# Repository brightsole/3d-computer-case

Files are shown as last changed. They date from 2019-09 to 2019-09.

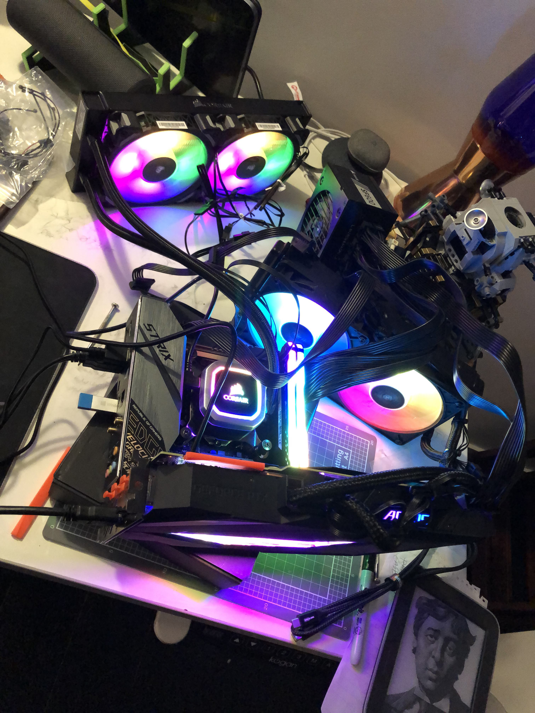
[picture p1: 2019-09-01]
photos/on-box-build.jpg

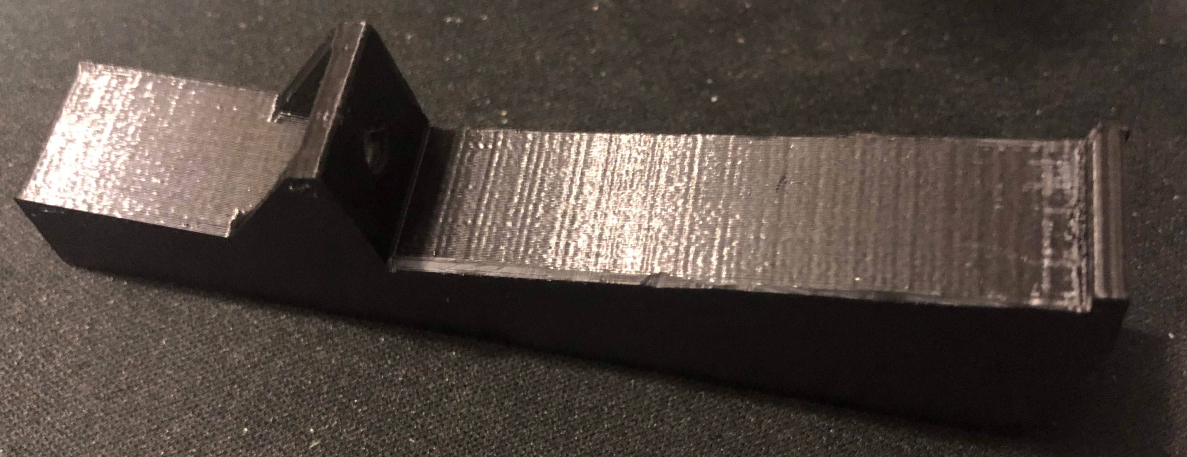
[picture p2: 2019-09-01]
photos/fan-foot-issues.jpg

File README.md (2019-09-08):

# 3d-computer-case

- [x] Describe
	- as small as possible to fit the mini-itx theme
	- hinge between mobo + gpu cowling & fan tower
	- dual fans in rear air column
	- cable hinge cowling
	- fully 3d printed V1
	- V2 more interconnected design with 3d printed moulds for fiberglass parts

- [x] buy parts [part picker basics](https://au.pcpartpicker.com/list/t6MXKB)

- [x] prep work
	- [x] connect all parts on-box build [photo](./photos/on-box-build.jpg)
	- [x] re-mount ram to solve post issue
	- [x] install os
	- [x] run benchmark

- [ ] Design V1
	- [x] mobo block
		- [x] base screw plate
	- [ ] gpu block
		- [x] base insert rest plate
		- [ ] power access block
	- [ ] hinge area
	- [x] interconnectors for blocks & block feet
	- [ ] flexible hinged cowling for watercooling channels

- [ ] Redesign issues found in V1
	- [x] mobo block [multiple](./photos/mobo-block-width-issues.jpg) [issues](./photos/mobo-block-screw-issue.jpg)
		- [x] too wide by 10mm 
		- [x] screw body width too small by 1mm
		- [x] under-gpu height too high by 1mm
		- [x] under-cowling support too short by 1.5mm
	- [x] mobo block [cowling support height issue](./photos/mobo-block-cowling-support-height-issue.jpg)
		- [x] under-cowling support now too high, especially to screw on back ([fixed by grinding, model corrected in V1.3](./photos/mobo-block-height-and-screw-issue.jpg))
		- [ ] TO FIX IN V2: screw walls have very little lateral strength because of vertical printing
	- [x] fans base foot [mild issues](./photos/fan-foot-issues.jpg)
		- [x] too narrow by 0.5mm
		- [x] front lip too short by 1.5mm
		- [x] sharp edges with elephant foot overhang, and screw height
	- [x] gpu block [major issue](./photos/gpu-block-issue.jpg)
		- [x] metal cowling hole too narrow

- [x] Print
	- [x] mobo block V1[.1](./files/mobo-holder-v1.1.stl)
	- [x] mobo block V1[.2](./files/mobo-holder-v1.2.stl) redesign
	- [x] fans base foot V1[.1](./files/fan-foot-v1.1.stl)
	- [x] fans base foot V1[.2](./files/fan-foot-v1.2.stl) redesign
	- [x] gpu block V1[.1](./files/gpu-block-v1.1.stl)

- [x] Describe Problems with V1
	- layout [very cluttered](./photos/v1-full-layout.jpg)
	- water cooling cables fight for space with psu cables
	- large space caused by flat gpu extension
	- good airflow; no dust protection
	- no blocks connected
	- no way to move, exposed dangerous places to touch
	- power switches not designed into any block
	- 3d printed plastic not durable
	- neglected to design psu connection block
	- hinge ideas scrapped after seeing pipe cluster

---

- [x] Describe V2
	- rotate cooling block 90° to reduce pipe congestion
	- elevate mobo and reduce lateral distance to gpu
	- connect gpu & mobo blocks
	- add handle to top of mobo/cooling tower
	- shorten cables, or create cable hiding tower hinge
	- add cutout to gpu block to insert power switches

- [ ] Redesign V2
	- [ ] back support structure with window for mobo
	- [ ] hinged front cowling for mobo
	- [ ] hollow structure for gpu & power switches

- [ ] print V2
	- [ ] gpu 1 || 2
	- [ ] mobo 1 || 3
	- [ ] psu connection system
	- [ ] cooling tower connectors/supports
	- [ ] handle

---

- [x] Describe V3
	- create designs that are predominantly moulding
	- design 3d printed parts that insert into fiberglass frame
	- buy clear pla+ or PETG for case colour spice
	- larger pieces in the shape of V2, but made of fiberglass with printed inserts, and structural rigidity created by folds

- [ ] Redesign V3

- [ ] print V3 mold pieces

- [ ] Print V3 inserts

---

- [ ] Cleanup

- [ ] Assemble
		- [x] [V1](./photos/v1-full-layout.jpg)

- [ ] Finish

- [ ] Photograph

- [ ] Thingiverse

- [ ] Software
	- [x] [Ninite - Install or Update Multiple Apps at Once](https://ninite.com/)
	- [x] Docker for win10
	- [x] WSL2 using `fast-ring` win10
	- [x] Ubuntu
	- [x] Zsh
	- [ ] our git/npm keys

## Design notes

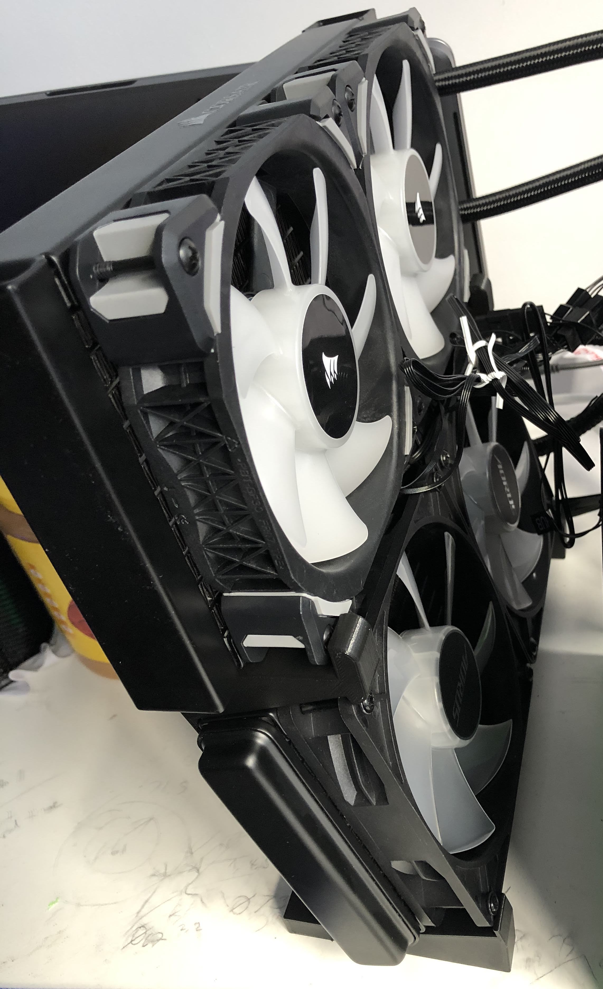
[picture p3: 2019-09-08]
photos/fan-block-front.jpg

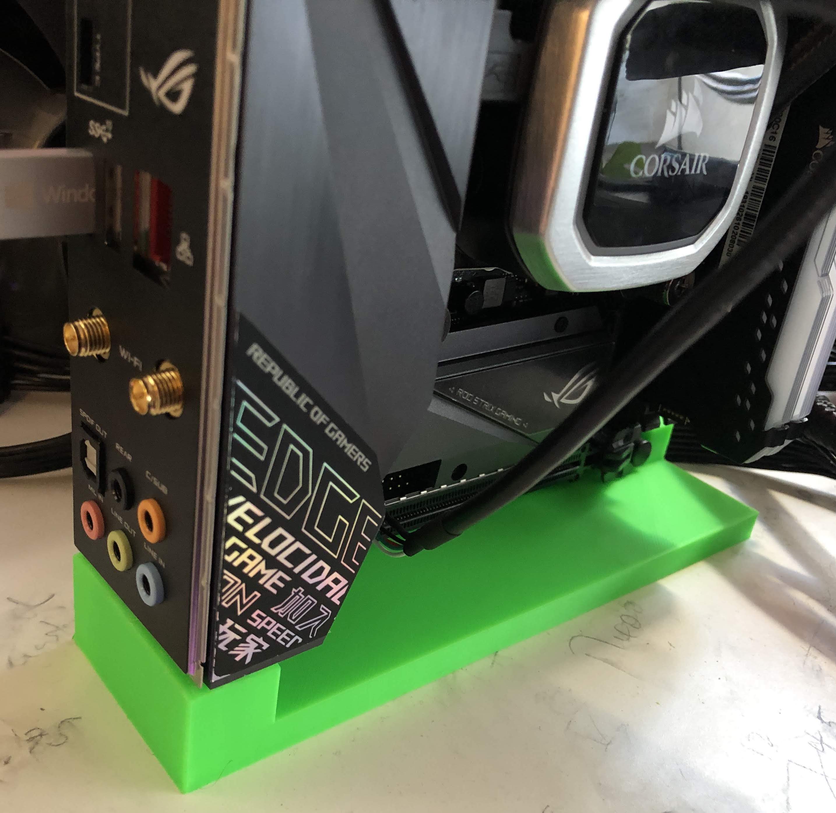
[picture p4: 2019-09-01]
photos/mobo-block-freestanding.jpg

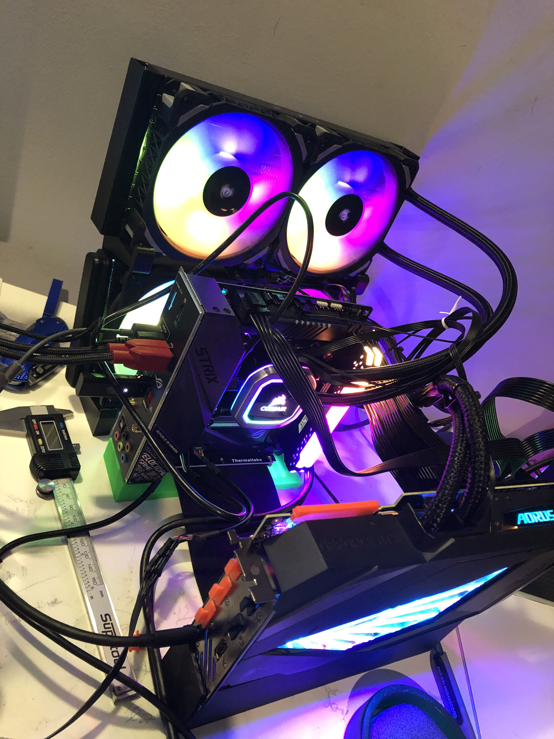
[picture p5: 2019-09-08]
photos/v1-full-layout.jpg

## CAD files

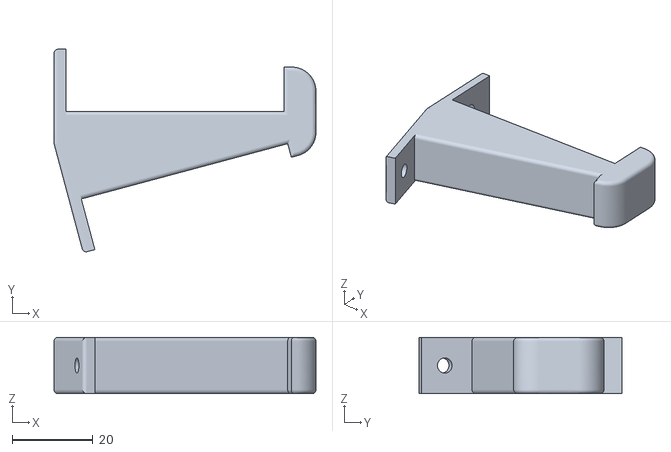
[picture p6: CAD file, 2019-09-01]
files/fan-hinge-v1.1.stl
65.0 x 50.3 x 14.0

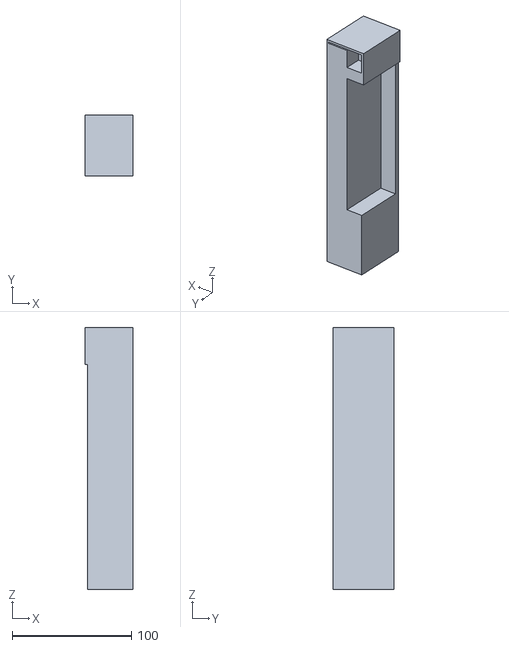
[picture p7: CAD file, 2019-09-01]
files/gpu-block-v1.1.stl
40.0 x 51.0 x 220.0

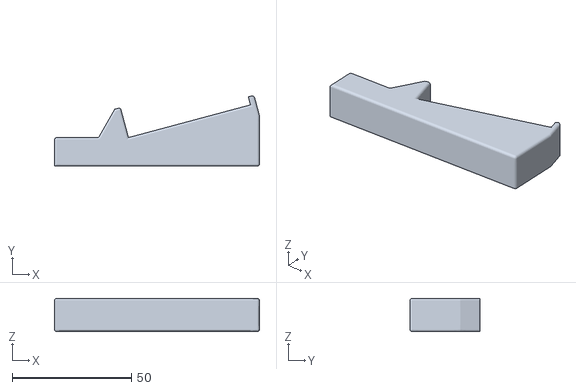
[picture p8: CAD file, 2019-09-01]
files/fan-foot-v1.2.stl
86.1 x 29.5 x 14.0

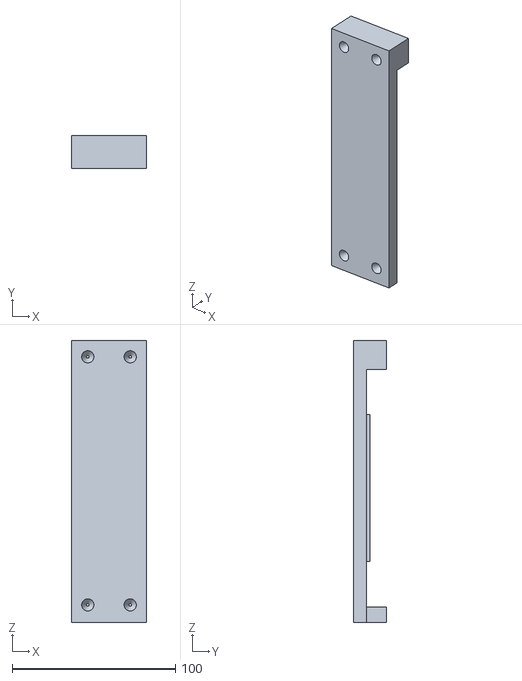
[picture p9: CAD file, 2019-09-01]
files/mobo-holder-v1.3.stl
46.0 x 20.0 x 172.8

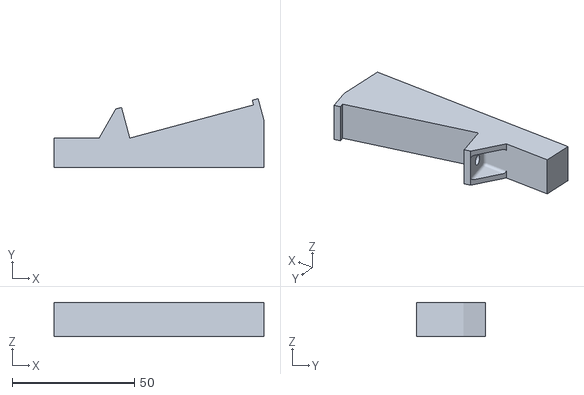
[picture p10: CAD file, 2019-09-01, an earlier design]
files/fan-foot-v1.1.stl
86.1 x 28.2 x 14.0

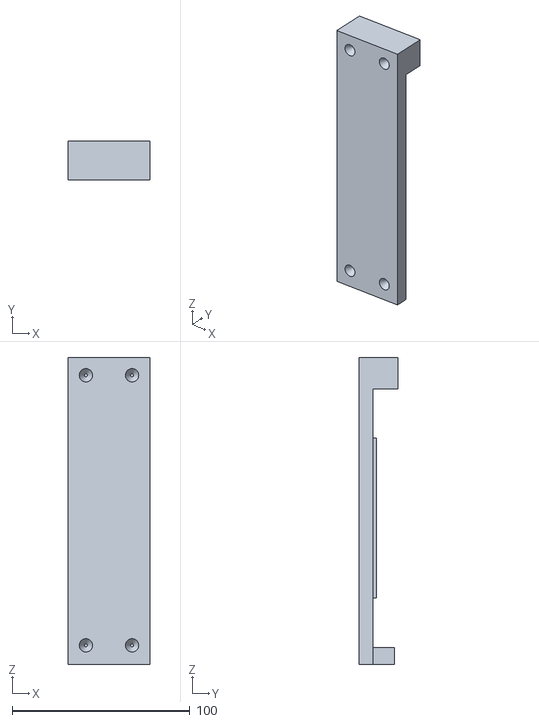
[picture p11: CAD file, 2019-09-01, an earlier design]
files/mobo-holder-v1.2.stl
46.0 x 22.0 x 172.8

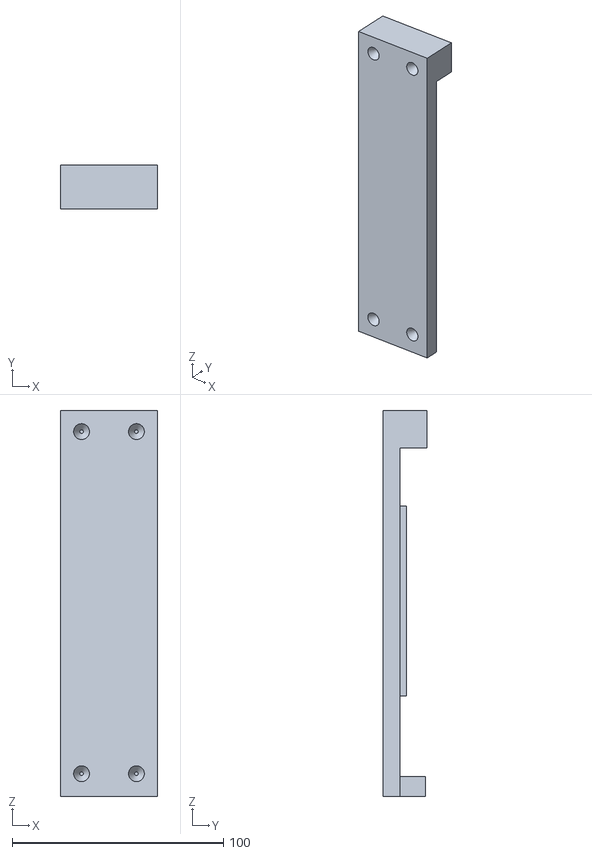
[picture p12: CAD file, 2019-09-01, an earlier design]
files/mobo-holder-v1.1.stl
46.0 x 20.8 x 182.8

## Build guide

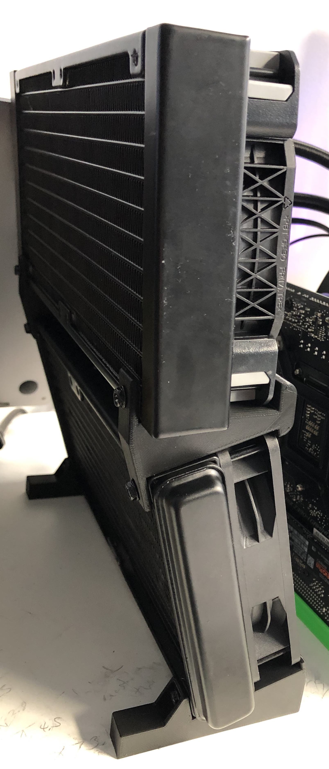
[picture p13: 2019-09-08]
photos/fan-block-assembly.jpg

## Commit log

2019-09-01 :sparkles: init commit with first part print!
    [mobo-holder.stl]
2019-09-01 :recycle: rename parts during v1.1 mobo reprint.
    [mobo-holder-v1.1.stl, mobo-holder-v1.2.stl]
2019-09-01 :recycle: mobo-holder-v1.3 patches.
    [mobo-holder-v1.3.stl]
2019-09-01 :sparkles: add fan+ and gpu designs.
    [fan-foot-v1.1.stl, fan-foot-v1.2.stl, fan-hinge-v1.1.stl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]
